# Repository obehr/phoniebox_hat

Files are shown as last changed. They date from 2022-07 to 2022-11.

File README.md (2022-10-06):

# phoniebox_hat
Raspberry Pi HAT for [RPi-Jukebox-RFID](https://github.com/MiczFlor/RPi-Jukebox-RFID)

In 2021 I built a Raspberry PI based Jukebox with RFID reader (see [here](https://github.com/MiczFlor/RPi-Jukebox-RFID/discussions/1331#discussioncomment-433065)). I used a breadboard for buttons and LEDs, USB sound card, ground loop isolator, PAM8403 amplifier. To disconnect the Raspberry from its USB power bank supply on shutdown, I used the awesome [OnOff SHIM](https://shop.pimoroni.com/products/onoff-shim) by Pimoroni.

This is a Raspberry Pi HAT for the 40W GPIO header. It integrates all of those functions on a single custom PCB:
 - DAC (PCM5102a)
 - Amplifier (PAM8406)
 - LED open drain buffers
 - Button inputs with hardware debounce
 - Screw clamps for connecting buttons and LEDs
 - Pin headers for RFID-RC522 and I2C
 - Battery disconnect circuit (the OnOff SHIM is awesome but I didn't want a separate PCB)
 - USB-C connector for power supply

The PCB complies to the official [HAT specification](https://github.com/raspberrypi/hats). Schematic and layout are done in KiCad 6.0. When ordering five PCBs including assembly at JLCPCB, one board costs around 18 USD.

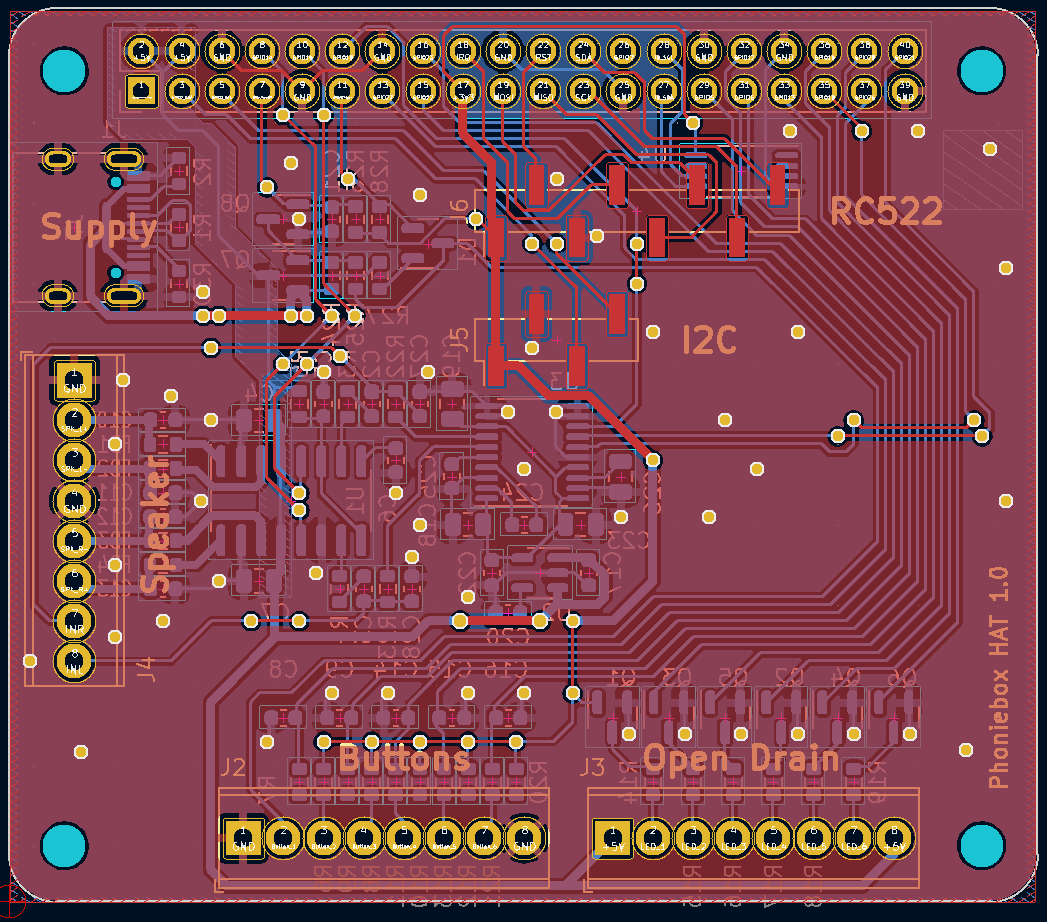
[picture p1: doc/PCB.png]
Screenshot of PCB


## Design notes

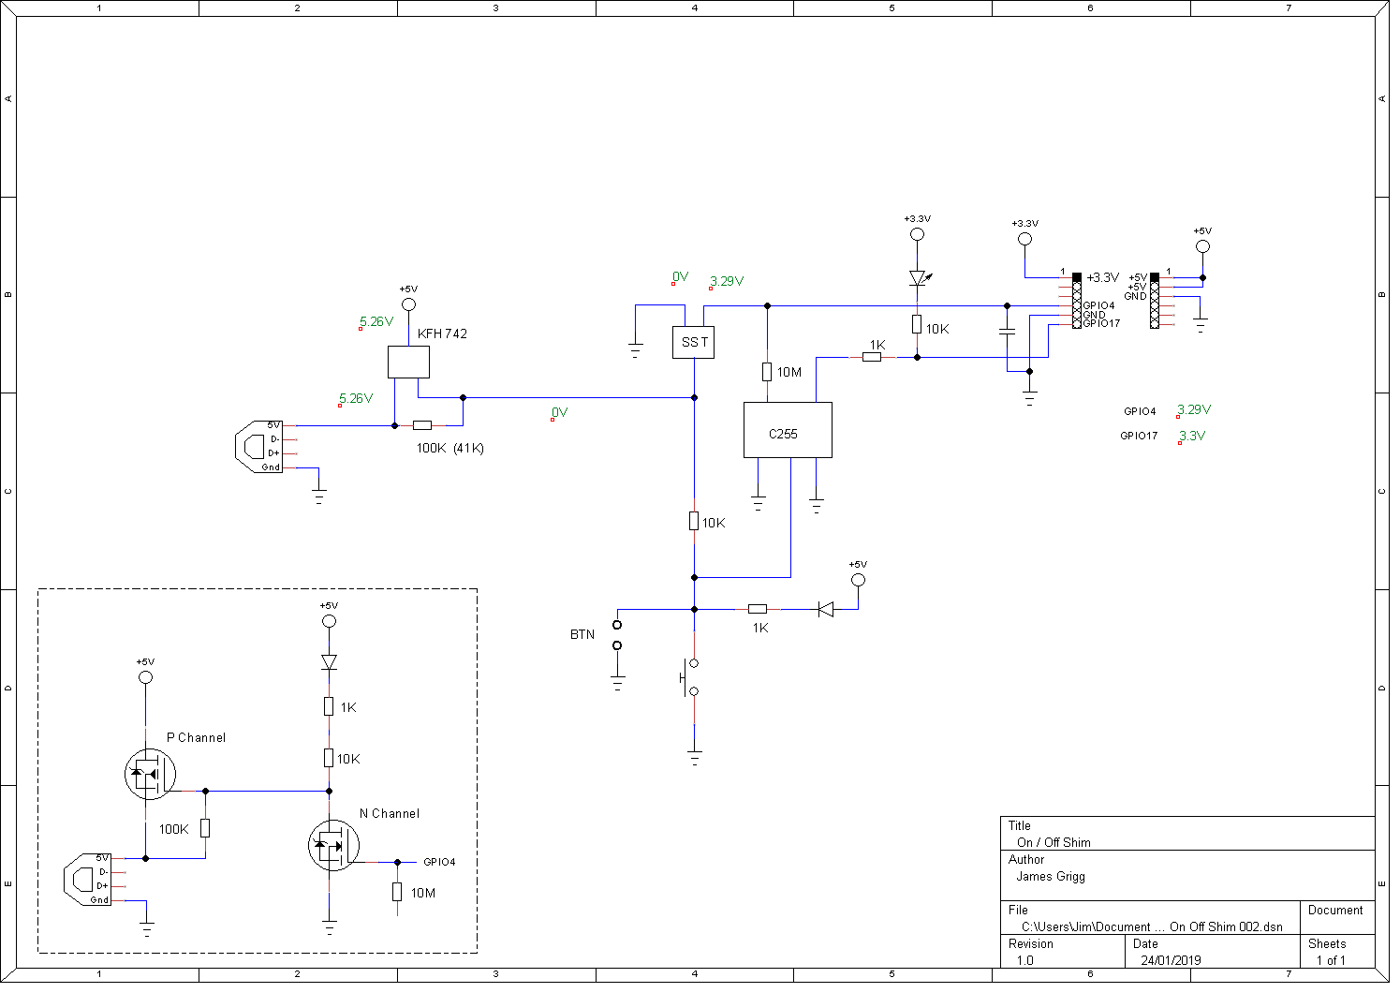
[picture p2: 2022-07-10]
doc/onoff-shim.png

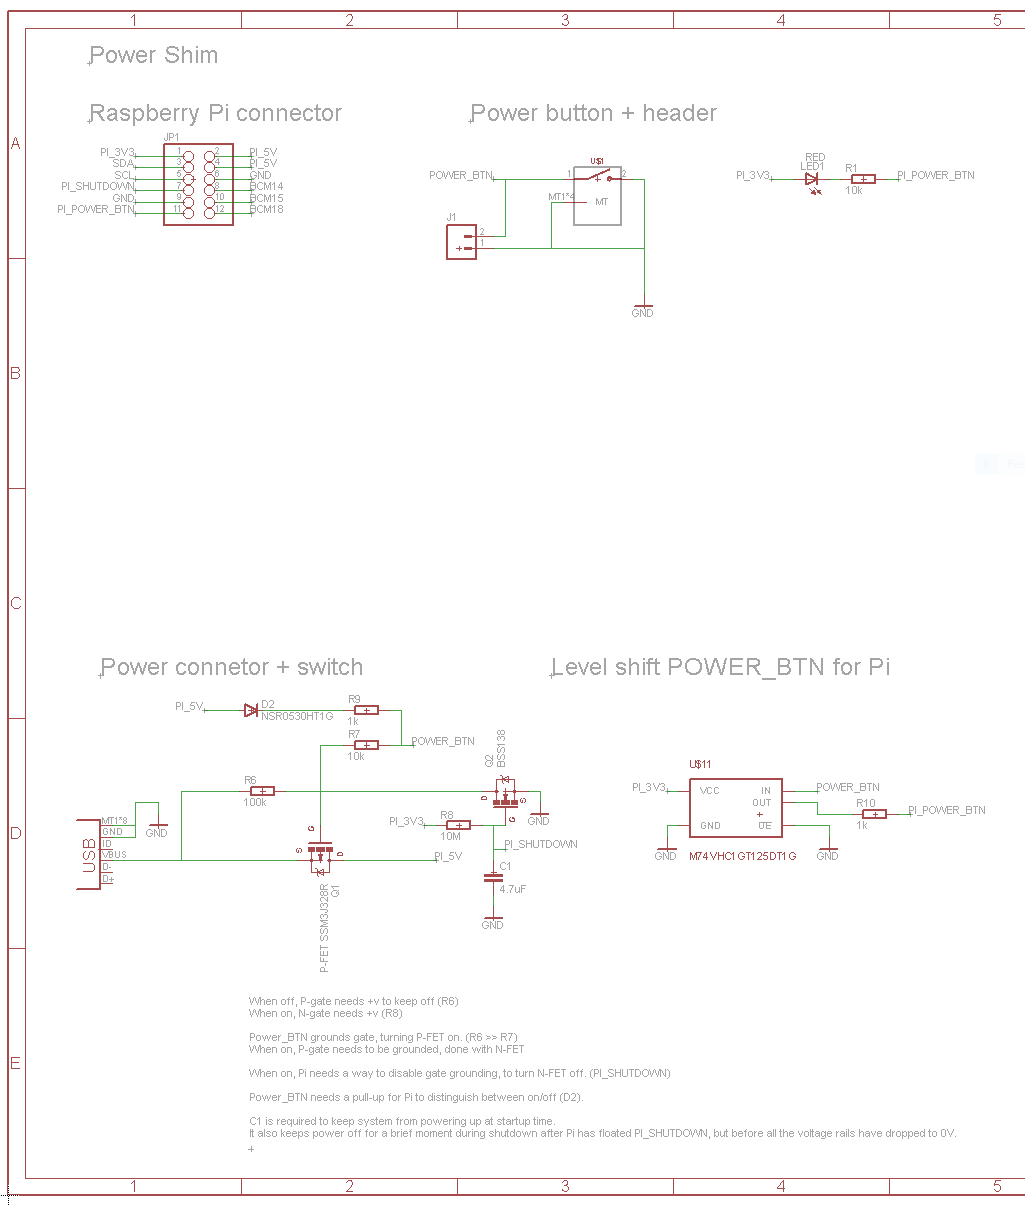
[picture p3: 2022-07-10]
doc/onoff-shim_official.png

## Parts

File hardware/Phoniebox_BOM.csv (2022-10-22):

Comment | Designator | Footprint | LCSC
220p | C10,C11,C12,C13 | Capacitor_SMD:C_0603_1608Metric
100n | C17,C20,C21,C22 | Capacitor_SMD:C_0603_1608Metric
1u | C2,C3,C5,C6,C8,C9,C14,C15,C16 | Capacitor_SMD:C_0603_1608Metric
4u7 | C24,C25 | Capacitor_SMD:C_0603_1608Metric
2n2 | C27,C28 | Capacitor_SMD:C_0603_1608Metric
10u | C4,C7,C18,C19,C23,C26 | Capacitor_SMD:C_0805_2012Metric
BAT54C | D1 | Package_TO_SOT_SMD:SOT-23 | C37704
FerriteBead_Small | FB1,FB2,FB3,FB4 | Resistor_SMD:R_0603_1608Metric | C354394
GPIO | J1 | Connector_PinSocket_2.54mm:PinSocket_2x20_P2.54mm_Vertical | C2977589
Screw_Terminal_01x08 | J2,J3,J4 | TerminalBlock_Phoenix:TerminalBlock_Phoenix_MPT-0,5-8-2.54_1x08_P2.54mm_Horizontal
Conn_01x04_Male | J5 | Connector_PinHeader_2.54mm:PinHeader_1x04_P2.54mm_Vertical_SMD_Pin1Left
Conn_01x08_Male | J6 | Connector_PinHeader_2.54mm:PinHeader_1x08_P2.54mm_Vertical_SMD_Pin1Left
USB_C_Receptacle_USB2.0 | J7 | Connector_USB:USB_C_Receptacle_HRO_TYPE-C-31-M-12 | C165948
2N7002 | Q1,Q2,Q3,Q4,Q5,Q6,Q8 | Package_TO_SOT_SMD:SOT-23 | C350313
AO3401A | Q7 | Package_TO_SOT_SMD:SOT-23 | C15127
10 | R1,R5 | Resistor_SMD:R_0603_1608Metric
100 | R11,R14,R15,R16,R17,R18,R19 | Resistor_SMD:R_0603_1608Metric
5k11 | R2,R30 | Resistor_SMD:R_0603_1608Metric
470 | R22,R23 | Resistor_SMD:R_0603_1608Metric
100k | R24,R26 | Resistor_SMD:R_0603_1608Metric
1k | R27,R28 | Resistor_SMD:R_0603_1608Metric
10k | R3,R4,R25,R29 | Resistor_SMD:R_0603_1608Metric
33k | R6,R7,R8,R9,R10,R12,R13,R20,R21 | Resistor_SMD:R_0603_1608Metric
PAM8406 | U1 | Package_SO:SOP-16_3.9x9.9mm_P1.27mm | C86270
TPS79333-EP | U2 | Package_TO_SOT_SMD:SOT-23-5 | C9840
PCM5102 | U3 | Package_SO:TSSOP-20_4.4x6.5mm_P0.65mm | C107671
CAT24C32 | U4 | Package_SO:TSSOP-8_4.4x3mm_P0.65mm | C94264

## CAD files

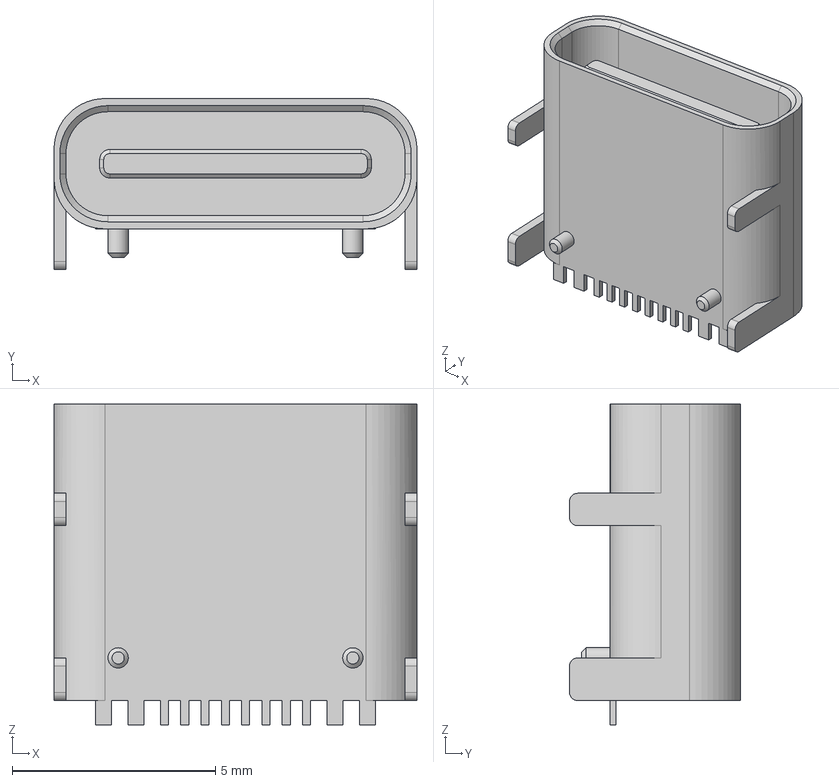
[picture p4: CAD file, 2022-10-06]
hardware/TYPE-C-31-M-12.stp
8.94 x 4.21 x 7.90 mm

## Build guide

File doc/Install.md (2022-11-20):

# Software installation

## OS

Tested with Raspberry Pi OS Lite

## Jukebox

Install RPi-Jukebox-RFID from https://github.com/MiczFlor/RPi-Jukebox-RFID/

The RC522 reader uses SPI0 and the default pin configuration. To configure, run ./run_register_reader.py in src/jukebox and submit the following inputs:

	Reader module number? -> 2 (MFRC522 via SPI)
	Install Python dependencies? -> y
	Auto-configure system settings? -> y
	SPI CEx (CE0=GPIO08, CE1=GPIO7)? -> 0
	IRQ GPIO pin (BCM numbering)? -> 24
	Reset GPIO pin (BCM numbering)? -> 25
	4-byte only legacy mode? -> n
	Do you want to add another RFID reader? -> n

## Battery disconnect circuit

The battery disconnect circuit is compatible with OnOffSHIM. Just run 
	
	curl https://get.pimoroni.com/onoffshim | bash

## Sound card
	
The sound card is compatible with HifiBerry MiniAmp. 

Remove the line

	dtparam=audio=on

from /boot/config.txt if it exists.

If your system uses the vc4-fkms-v3d overlay, make sure, audio is also disabled on this:

	dtoverlay=vc4-fkms-v3d,audio=off

Edit /boot/config.txt and add the following line:

	dtoverlay=hifiberry-dac

Edit or create /etc/asound.conf:

	pcm.hifiberry {
			  type softvol
			  slave.pcm "plughw:0"
			  control.name "Master"
			  control.card 0
	  } 
	pcm.!default {
			  type plug
			  slave.pcm "hifiberry"
	  }

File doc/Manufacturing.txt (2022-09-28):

Generating Gerber Files
---------------------------------------

... and also drill files...

See https://support.jlcpcb.com/article/194-how-to-generate-gerber-and-drill-files-in-kicad-6

Generating BOM and centroid file
---------------------------------------

See https://support.jlcpcb.com/article/84-how-to-generate-the-bom-and-centroid-file-from-kicad

Run script through Schematic editor -> Tools -> Create BOM

Export pos file. Remember to rename columns according to JLC article

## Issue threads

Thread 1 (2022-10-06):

Todo-List before ordering

obehr, 2022-10-06:
The following things should be done before ordering the PCB:

- [ ] Check compliance to Raspberry Pi HAT [specification](https://github.com/raspberrypi/hats)
- [ ] Verify battery disconnect circuit function (prototype and/or simulation)
- [ ] Check DAC circuit according to datasheet / typical application
- [ ] Check Amplifier circuit according to datasheet / typical application
- [ ] Connection of DAC and Amp - will it work like this?
- [ ] Filter size for button debouncing ok or too big?
- [ ] Confirm USB-C connection. Does it allow to draw 3A @ 5V?

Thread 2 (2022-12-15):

All GPIOs driving open drain MOSFETs should have pull-down characteristic

obehr, 2022-12-15:
With pull-down characteristic the open drain output will switch on during startup.

BCM pins GPIO0-GPIO8 have pull-up characteristic by default. Others have pull-down.

GPIO6 is used for Open Drain #1. It should be replaced by any other GPIO > #8.

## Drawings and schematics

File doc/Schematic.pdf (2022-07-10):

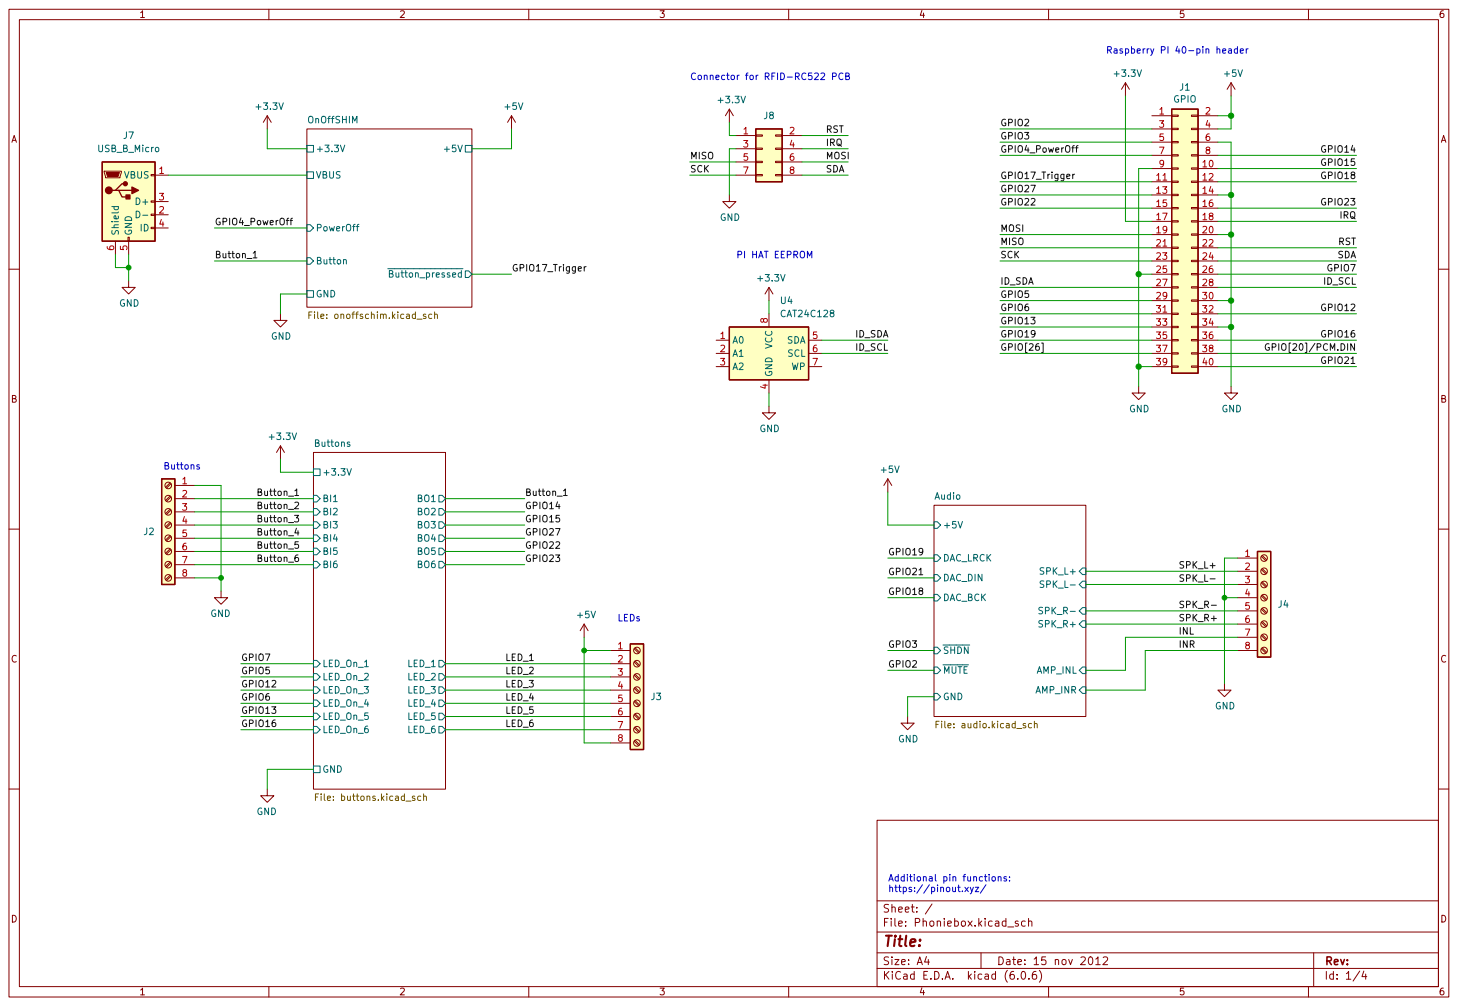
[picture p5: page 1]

Raspberry PI 40-pin header
IRQ

Connector for RFID-RC522 PCB
+3.3V GND

15 | 16 18 20
17

INL PI HAT EEPROM

4 SDA 5 SCL 6 WP 7 VCC

https://pinout.xyz/ LEDs

INR | 8

LED_3 | 4

LED_5 | 6
LED_6 | 7

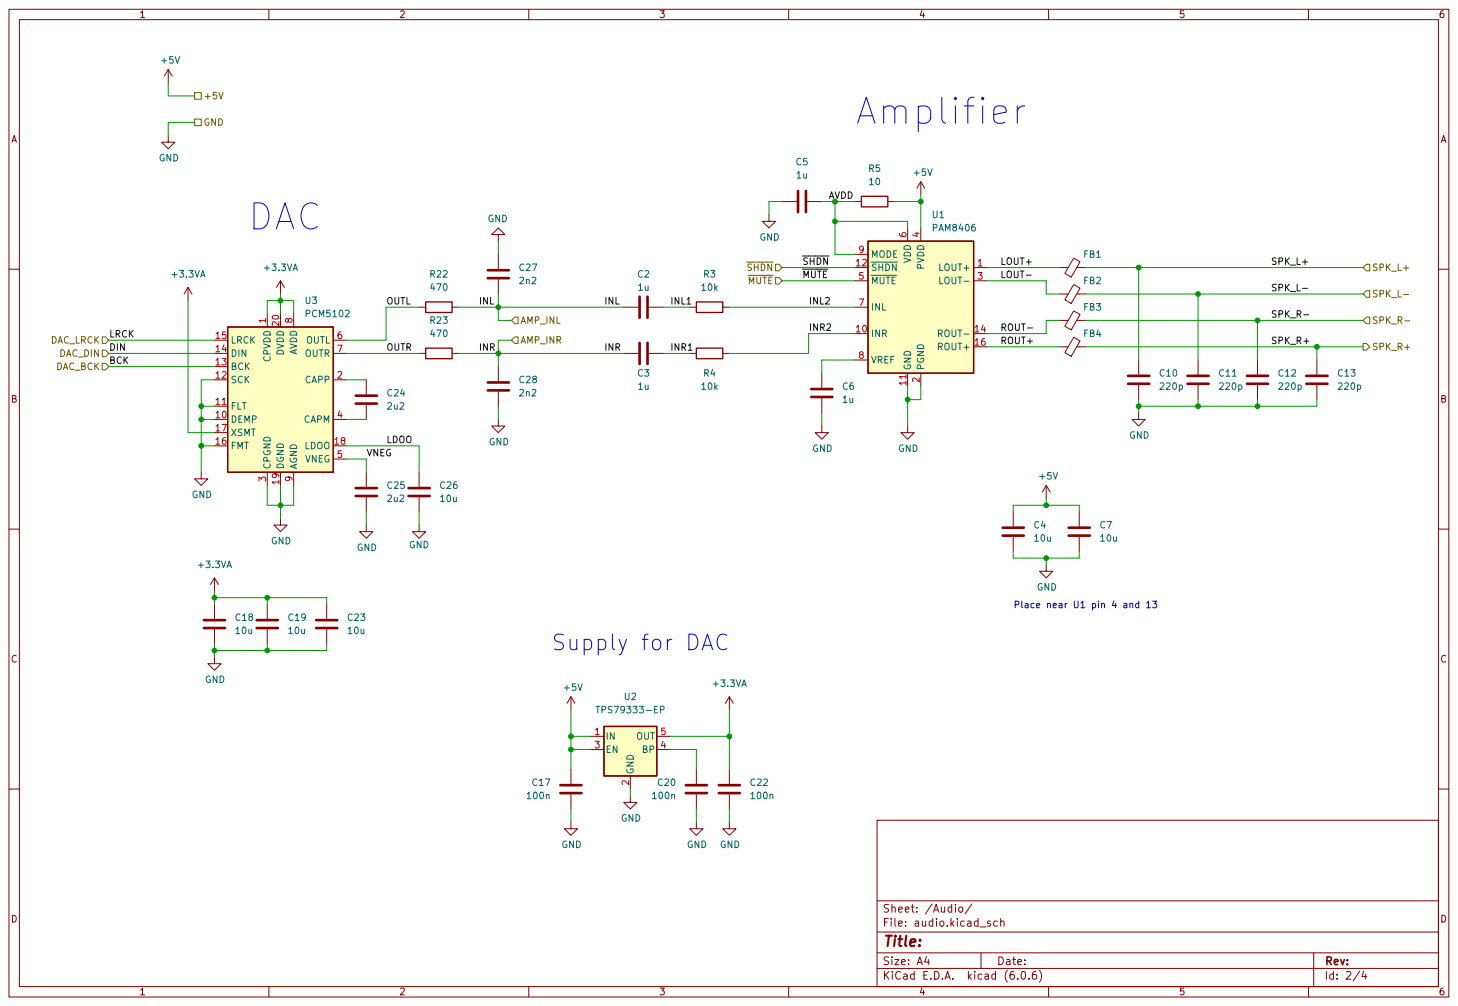
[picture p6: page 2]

1 DEMP 10 FLT 11 SCK 12 BCK 13 DIN 14

3 CAPM 4 VNEG 5 OUTL 6 OUTR 7 AVDD

Place near U1 pin 4 and 13

2 EN 3 BP 4 OUT 5 U2 TPS79333-EP

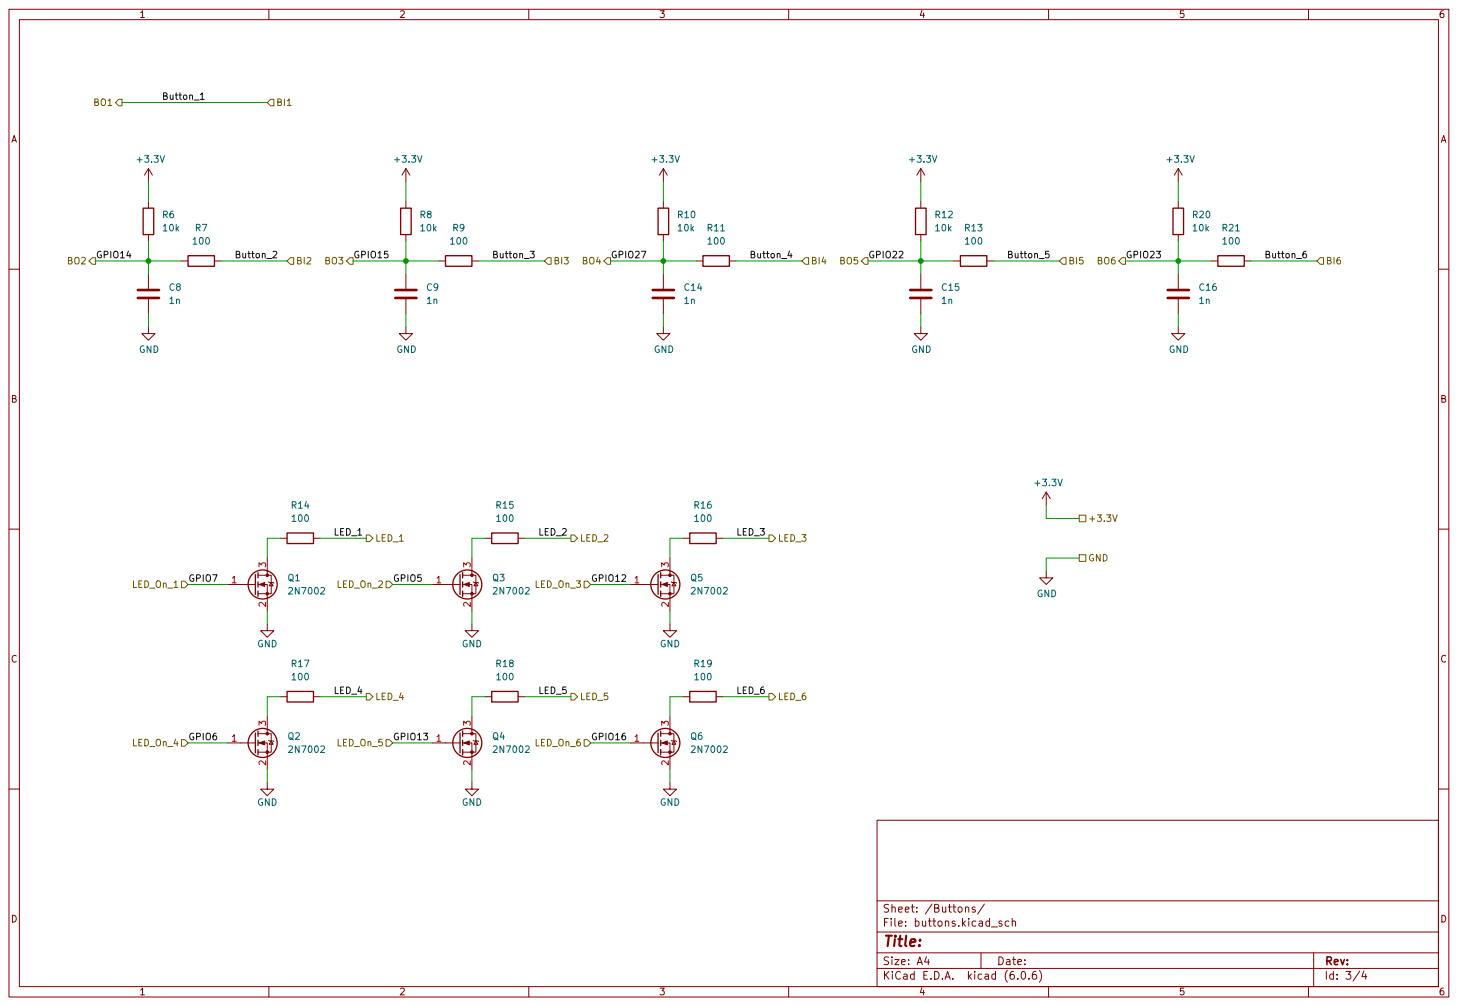
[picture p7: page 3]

File: buttons.kicad_sch Sheet: /Buttons/ R16

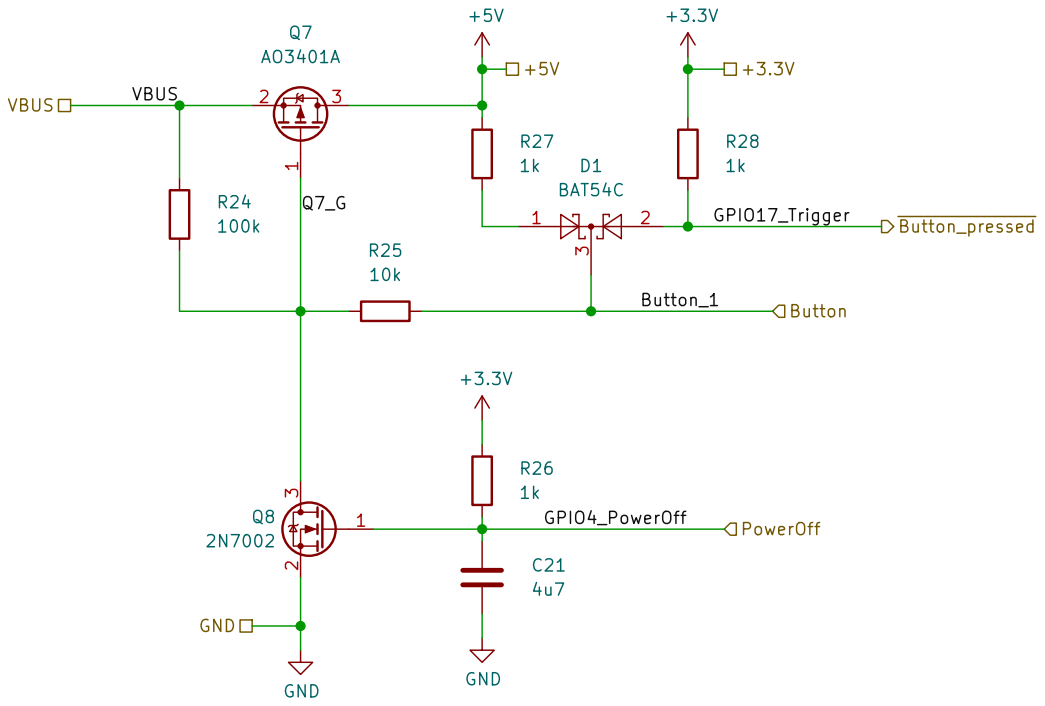
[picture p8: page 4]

File: onoffschim.kicad_sch Sheet: /OnOffSHIM/ GND

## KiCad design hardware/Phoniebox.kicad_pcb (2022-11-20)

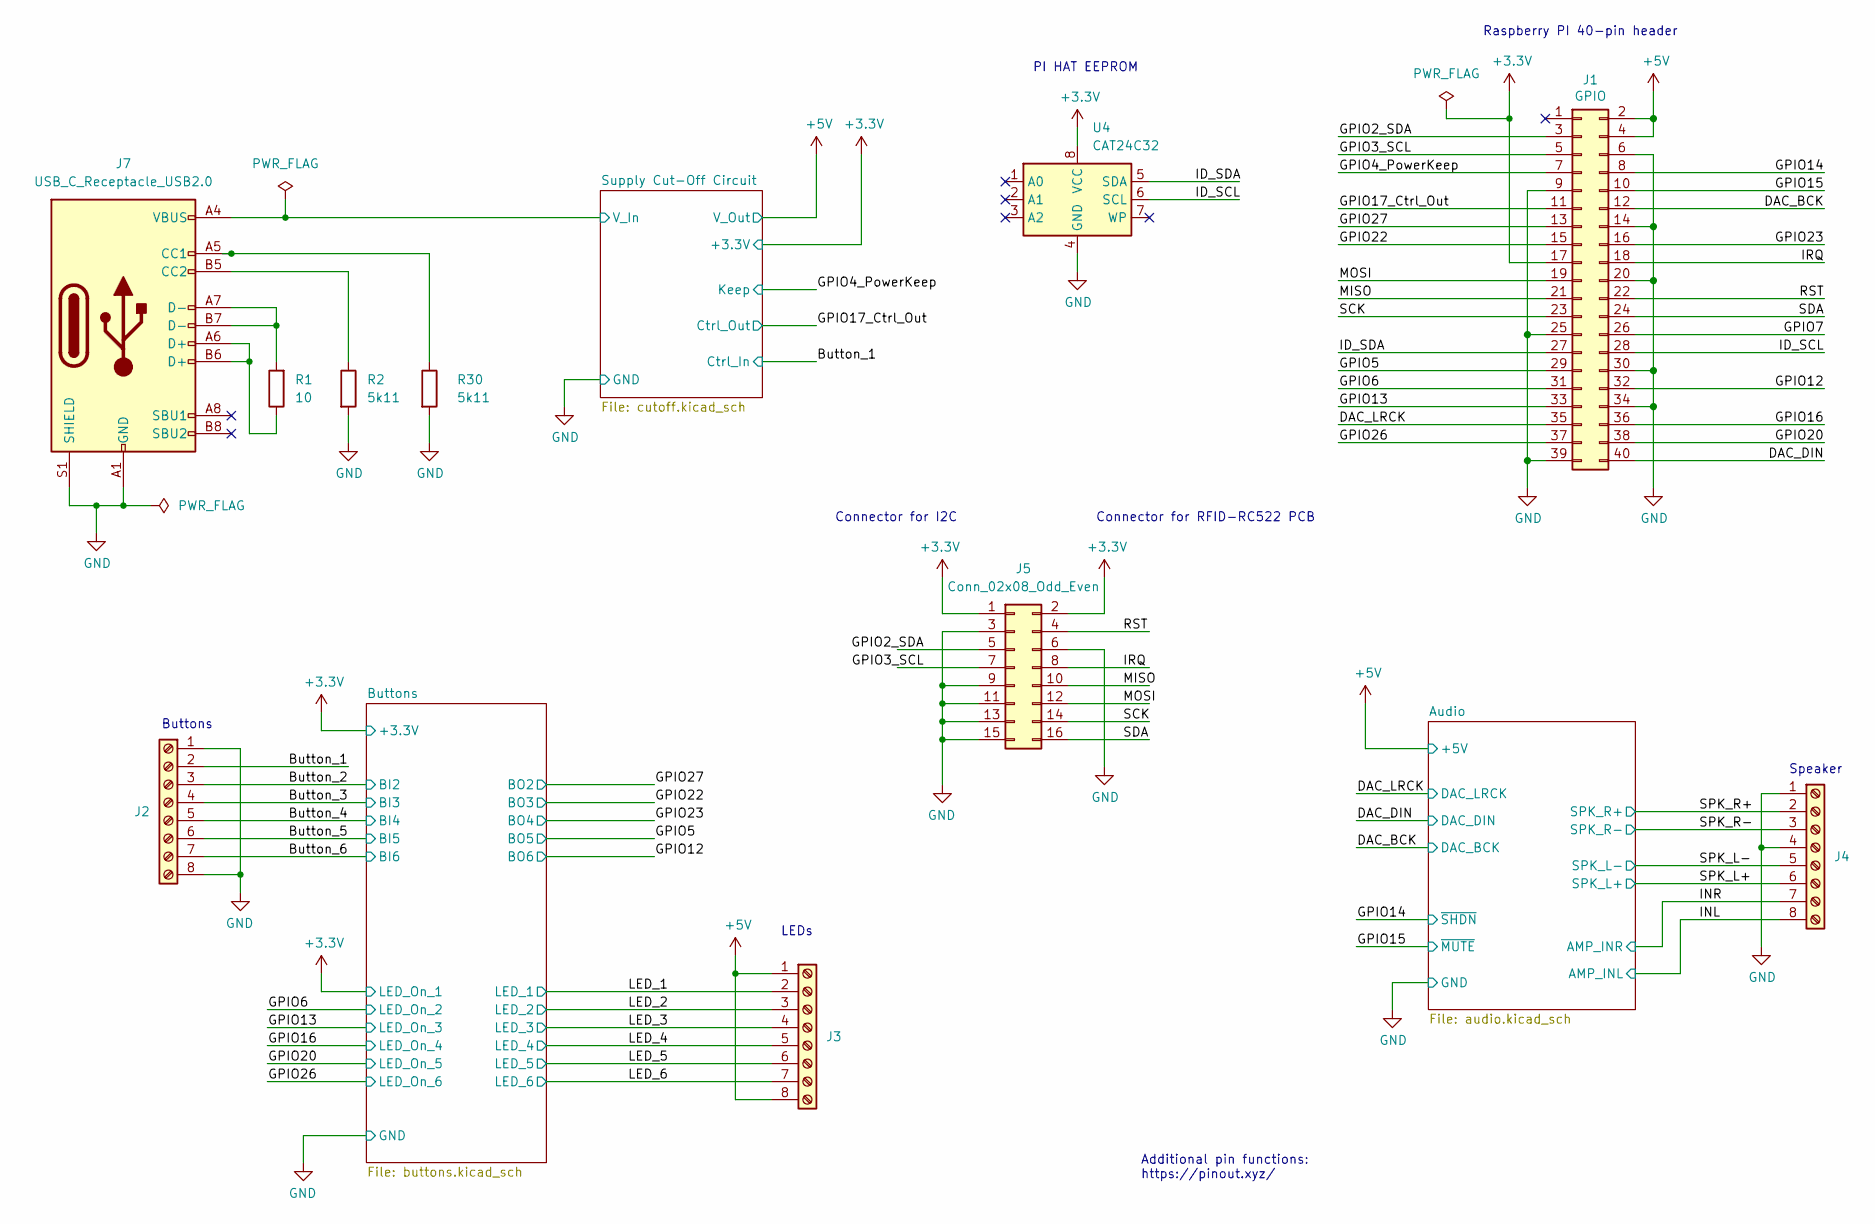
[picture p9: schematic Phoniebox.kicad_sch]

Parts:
J1: GPIO; PinSocket_2x20_P2.54mm_Vertical; LCSC C2977589
J2, J3, J4: Screw_Terminal_01x08; TerminalBlock_Phoenix_MPT-0,5-8-2.54_1x08_P2.54mm_Horizontal
J5: Conn_02x08_Odd_Even; PinHeader_2x08_P2.54mm_Vertical_SMD
J7: USB_C_Receptacle_USB2.0; USB_C_Receptacle_HRO_TYPE-C-31-M-12; LCSC C165948
R1: 10; R_0603_1608Metric
R2, R30: 5k11; R_0603_1608Metric
U4: CAT24C32; TSSOP-8_4.4x3mm_P0.65mm; LCSC C94264

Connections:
+3.3V: J1.17, J5.1, J5.2, U4.8 (VCC); also elsewhere on the board
+5V: J1.2, J1.4, J3.1, J3.8; also elsewhere on the board
/Button_1: J2.2; also elsewhere on the board
/Button_2: J2.3; also elsewhere on the board
/Button_3: J2.4; also elsewhere on the board
/Button_4: J2.5; also elsewhere on the board
/Button_5: J2.6; also elsewhere on the board
/Button_6: J2.7; also elsewhere on the board
/DAC_BCK: J1.12; also elsewhere on the board
/DAC_DIN: J1.40; also elsewhere on the board
/DAC_LRCK: J1.35; also elsewhere on the board
/GPIO2_SDA: J1.3, J5.5
/GPIO3_SCL: J1.5, J5.7
/GPIO4_PowerKeep: J1.7; also elsewhere on the board
/GPIO5: J1.29; also elsewhere on the board
/GPIO6: J1.31; also elsewhere on the board
/GPIO7: J1.26
/GPIO12: J1.32; also elsewhere on the board
/GPIO13: J1.33; also elsewhere on the board
/GPIO14: J1.8; also elsewhere on the board
/GPIO15: J1.10; also elsewhere on the board
/GPIO16: J1.36; also elsewhere on the board
/GPIO17_Ctrl_Out: J1.11; also elsewhere on the board
/GPIO20: J1.38; also elsewhere on the board
/GPIO22: J1.15; also elsewhere on the board
/GPIO23: J1.16; also elsewhere on the board
/GPIO26: J1.37; also elsewhere on the board
/GPIO27: J1.13; also elsewhere on the board
/ID_SCL: J1.28, U4.6 (SCL)
/ID_SDA: J1.27, U4.5 (SDA)
/INL: J4.8; also elsewhere on the board
/INR: J4.7; also elsewhere on the board
/IRQ: J1.18, J5.8
/LED_1: J3.2; also elsewhere on the board
/LED_2: J3.3; also elsewhere on the board
/LED_3: J3.4; also elsewhere on the board
/LED_4: J3.5; also elsewhere on the board
/LED_5: J3.6; also elsewhere on the board
/LED_6: J3.7; also elsewhere on the board
/MISO: J1.21, J5.10
/MOSI: J1.19, J5.12
/RST: J1.22, J5.4
/SCK: J1.23, J5.14
/SDA: J1.24, J5.16
/SPK_L+: J4.6; also elsewhere on the board
/SPK_L-: J4.5; also elsewhere on the board
/SPK_R+: J4.2; also elsewhere on the board
/SPK_R-: J4.3; also elsewhere on the board
/Supply Cut-Off Circuit/V_In: J7.A4 (VBUS), J7.A9 (VBUS), J7.B4 (VBUS), J7.B9 (VBUS); also elsewhere on the board
GND: J1.6, J1.9, J1.14, J1.20, J1.25, J1.30, J1.34, J1.39, J2.1, J2.8, J4.1, J4.4, J5.3, J5.6, J5.9, J5.11, J5.13, J5.15, J7.A1 (GND), J7.A12 (GND), J7.B1 (GND), J7.B12 (GND), J7.S1 (SHIELD), R2.2, R30.2, U4.4 (GND); also elsewhere on the board
unnamed: J7.A5 (CC1), R30.1
unnamed: J7.A6 (D+), J7.B6 (D+), R1.1
unnamed: J7.A7 (D-), J7.B7 (D-), R1.2
unnamed: J7.B5 (CC2), R2.1

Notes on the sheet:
Raspberry PI 40-pin header
Buttons
Additional pin functions: https://pinout.xyz/
LEDs
Connector for RFID-RC522 PCB
Speaker
PI HAT EEPROM
Connector for I2C

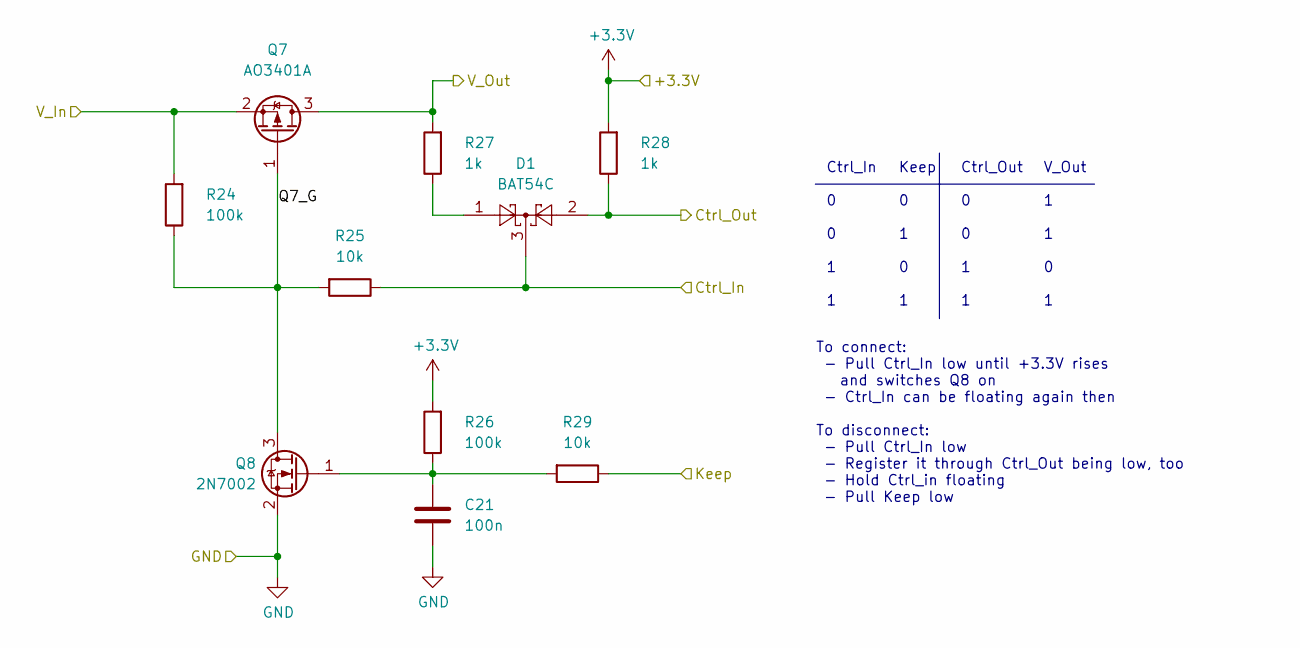
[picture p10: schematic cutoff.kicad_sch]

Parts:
C21: 100n; C_0603_1608Metric
D1: BAT54C; SOT-23; LCSC C37704
Q7: AO3401A; SOT-23; LCSC C15127
Q8: 2N7002; SOT-23; LCSC C350313
R24, R26: 100k; R_0603_1608Metric
R25, R29: 10k; R_0603_1608Metric
R27, R28: 1k; R_0603_1608Metric

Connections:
+3.3V: R26.2, R28.2; also elsewhere on the board
+5V: Q7.3 (D), R27.2; also elsewhere on the board
/Button_1: D1.3, R25.1; also elsewhere on the board
/GPIO4_PowerKeep: R29.1; also elsewhere on the board
/GPIO17_Ctrl_Out: D1.2, R28.1; also elsewhere on the board
/Supply Cut-Off Circuit/Q7_G: Q7.1 (G), Q8.3 (D), R24.1, R25.2
/Supply Cut-Off Circuit/V_In: Q7.2 (S), R24.2; also elsewhere on the board
GND: C21.2, Q8.2 (S); also elsewhere on the board
unnamed: C21.1, Q8.1 (G), R26.1, R29.2
unnamed: D1.1, R27.1

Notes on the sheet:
Ctrl_In 0 0 1 1
V_Out 1 1 0 1
Keep 0 1 0 1
Ctrl_Out 0 0 1 1
To connect: - Pull Ctrl_In low until +3.3V rises and switches Q8 on - Ctrl_In can be floating again then To disconnect: - Pull Ctrl_In low - Register it through Ctrl_Out being low, too - Hold Ctrl_in floating - Pull Keep low

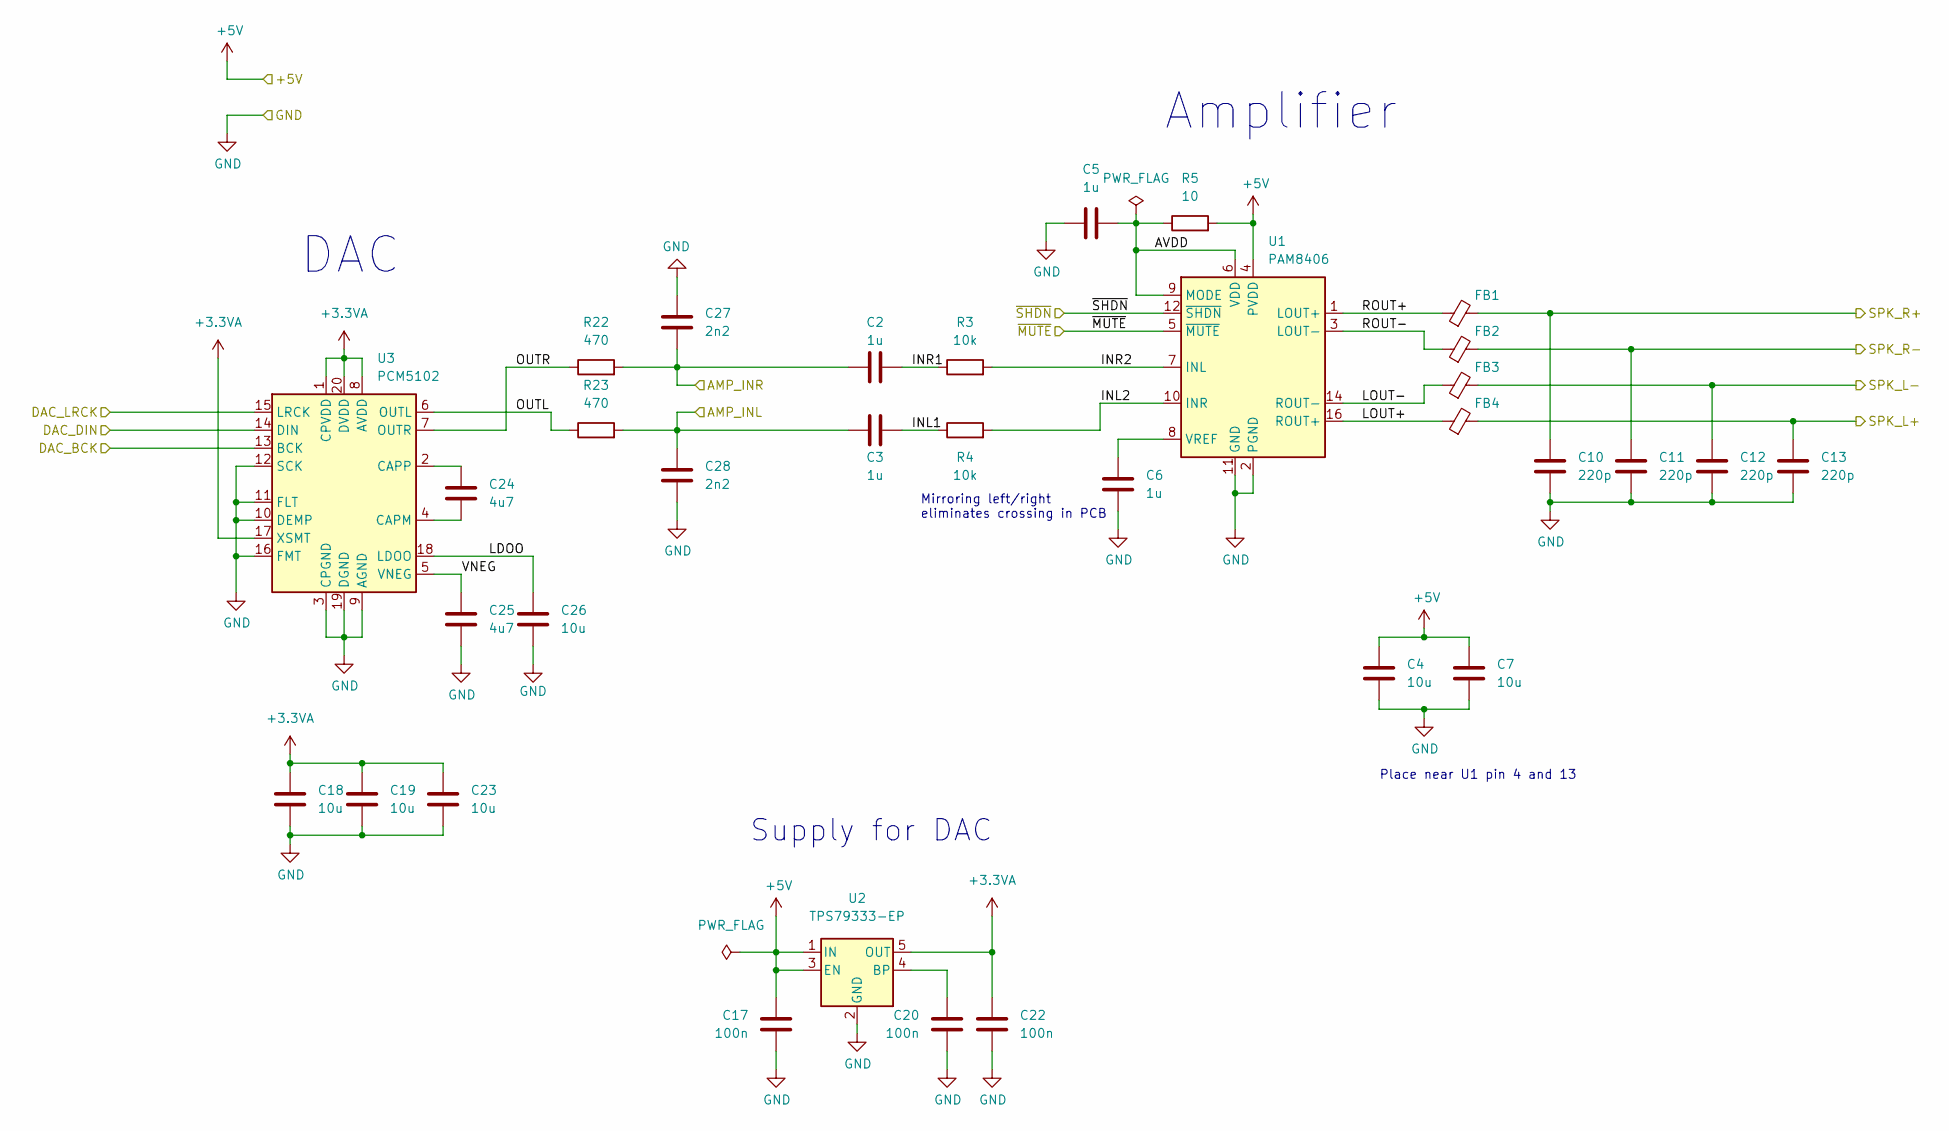
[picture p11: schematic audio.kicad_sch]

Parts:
C2, C3, C5, C6: 1u; C_0603_1608Metric
C4, C7, C18, C19, C23, C26: 10u; C_0805_2012Metric
C10, C11, C12, C13: 220p; C_0603_1608Metric
C17, C20, C22: 100n; C_0603_1608Metric
C24, C25: 4u7; C_0603_1608Metric
C27, C28: 2n2; C_0603_1608Metric
FB1, FB2, FB3, FB4: FerriteBead_Small; R_0603_1608Metric; LCSC C354394
R3, R4: 10k; R_0603_1608Metric
R5: 10; R_0603_1608Metric
R22, R23: 470; R_0603_1608Metric
U1: PAM8406; SOP-16_3.9x9.9mm_P1.27mm; LCSC C86270
U2: TPS79333-EP; SOT-23-5; LCSC C9840
U3: PCM5102; TSSOP-20_4.4x6.5mm_P0.65mm; LCSC C107671

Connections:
+3.3VA: C18.1, C19.1, C22.2, C23.1, U2.5 (OUT), U3.1 (CPVDD), U3.8 (AVDD), U3.17 (XSMT), U3.20 (DVDD)
+5V: C4.1, C7.1, C17.2, R5.2, U1.4 (PVDD), U1.13 (PVDD), U2.1 (IN), U2.3 (EN); also elsewhere on the board
/Audio/AVDD: C5.2, R5.1, U1.6 (VDD), U1.9 (MODE)
/Audio/INL1: C3.2, R4.1
/Audio/INL2: R4.2, U1.10 (INR)
/Audio/INR1: C2.2, R3.1
/Audio/INR2: R3.2, U1.7 (INL)
/Audio/LDOO: C26.1, U3.18 (LDOO)
/Audio/LOUT+: FB4.1, U1.16 (ROUT+)
/Audio/LOUT-: FB3.1, U1.14 (ROUT-)
/Audio/OUTL: R23.1, U3.6 (OUTL)
/Audio/OUTR: R22.1, U3.7 (OUTR)
/Audio/ROUT+: FB1.1, U1.1 (LOUT+)
/Audio/ROUT-: FB2.1, U1.3 (LOUT-)
/Audio/VNEG: C25.1, U3.5 (VNEG)
/DAC_BCK: U3.13 (BCK); also elsewhere on the board
/DAC_DIN: U3.14 (DIN); also elsewhere on the board
/DAC_LRCK: U3.15 (LRCK); also elsewhere on the board
/GPIO14: U1.12 (~SHDN); also elsewhere on the board
/GPIO15: U1.5 (~MUTE); also elsewhere on the board
/INL: C3.1, C28.1, R23.2; also elsewhere on the board
/INR: C2.1, C27.2, R22.2; also elsewhere on the board
/SPK_L+: C13.1, FB4.2; also elsewhere on the board
/SPK_L-: C12.1, FB3.2; also elsewhere on the board
/SPK_R+: C10.1, FB1.2; also elsewhere on the board
/SPK_R-: C11.1, FB2.2; also elsewhere on the board
GND: C4.2, C5.1, C6.2, C7.2, C10.2, C11.2, C12.2, C13.2, C17.1, C18.2, C19.2, C20.1, C22.1, C23.2, C25.2, C26.2, C27.1, C28.2, U1.2 (PGND), U1.11 (GND), U1.15 (PGND), U2.2 (GND), U3.3 (CPGND), U3.9 (AGND), U3.10 (DEMP), U3.11 (FLT), U3.12 (SCK), U3.16 (FMT), U3.19 (DGND); also elsewhere on the board
unnamed: C6.1, U1.8 (VREF)
unnamed: C20.2, U2.4 (BP)
unnamed: C24.1, U3.2 (CAPP)
unnamed: C24.2, U3.4 (CAPM)

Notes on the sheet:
DAC
Supply for DAC
Place near U1 pin 4 and 13
Mirroring left/right eliminates crossing in PCB
Amplifier

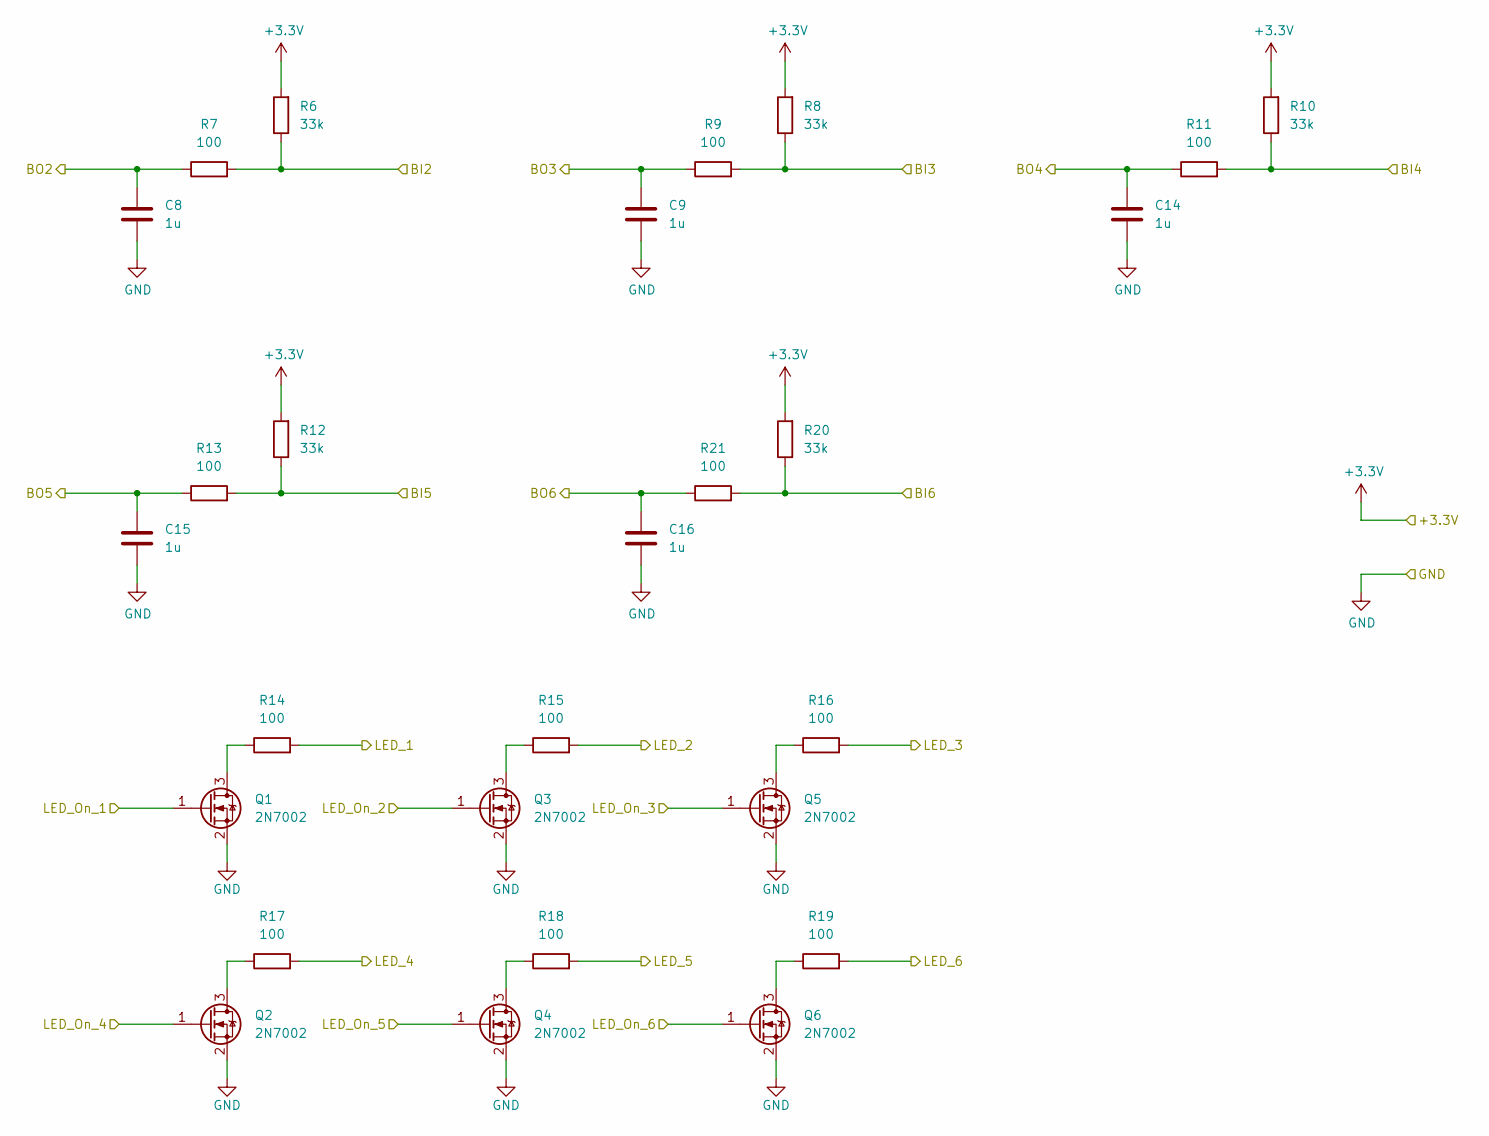
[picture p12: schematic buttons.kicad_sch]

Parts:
C8, C9, C14, C15, C16: 1u; C_0603_1608Metric
Q1, Q2, Q3, Q4, Q5, Q6: 2N7002; SOT-23; LCSC C350313
R6, R8, R10, R12, R20: 33k; R_0603_1608Metric
R7, R9, R11, R13, R14, R15, R16, R17, R18, R19, R21: 100; R_0603_1608Metric

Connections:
+3.3V: Q1.1 (G), R6.2, R8.2, R10.2, R12.2, R20.2; also elsewhere on the board
/Button_2: R6.1, R7.2; also elsewhere on the board
/Button_3: R8.1, R9.2; also elsewhere on the board
/Button_4: R10.1, R11.2; also elsewhere on the board
/Button_5: R12.1, R13.2; also elsewhere on the board
/Button_6: R20.1, R21.2; also elsewhere on the board
/GPIO5: C15.1, R13.1; also elsewhere on the board
/GPIO6: Q3.1 (G); also elsewhere on the board
/GPIO12: C16.1, R21.1; also elsewhere on the board
/GPIO13: Q5.1 (G); also elsewhere on the board
/GPIO16: Q2.1 (G); also elsewhere on the board
/GPIO20: Q4.1 (G); also elsewhere on the board
/GPIO22: C9.1, R9.1; also elsewhere on the board
/GPIO23: C14.1, R11.1; also elsewhere on the board
/GPIO26: Q6.1 (G); also elsewhere on the board
/GPIO27: C8.1, R7.1; also elsewhere on the board
/LED_1: R14.2; also elsewhere on the board
/LED_2: R15.2; also elsewhere on the board
/LED_3: R16.2; also elsewhere on the board
/LED_4: R17.2; also elsewhere on the board
/LED_5: R18.2; also elsewhere on the board
/LED_6: R19.2; also elsewhere on the board
GND: C8.2, C9.2, C14.2, C15.2, C16.2, Q1.2 (S), Q2.2 (S), Q3.2 (S), Q4.2 (S), Q5.2 (S), Q6.2 (S); also elsewhere on the board
unnamed: Q1.3 (D), R14.1
unnamed: Q2.3 (D), R17.1
unnamed: Q3.3 (D), R15.1
unnamed: Q4.3 (D), R18.1
unnamed: Q5.3 (D), R16.1
unnamed: Q6.3 (D), R19.1

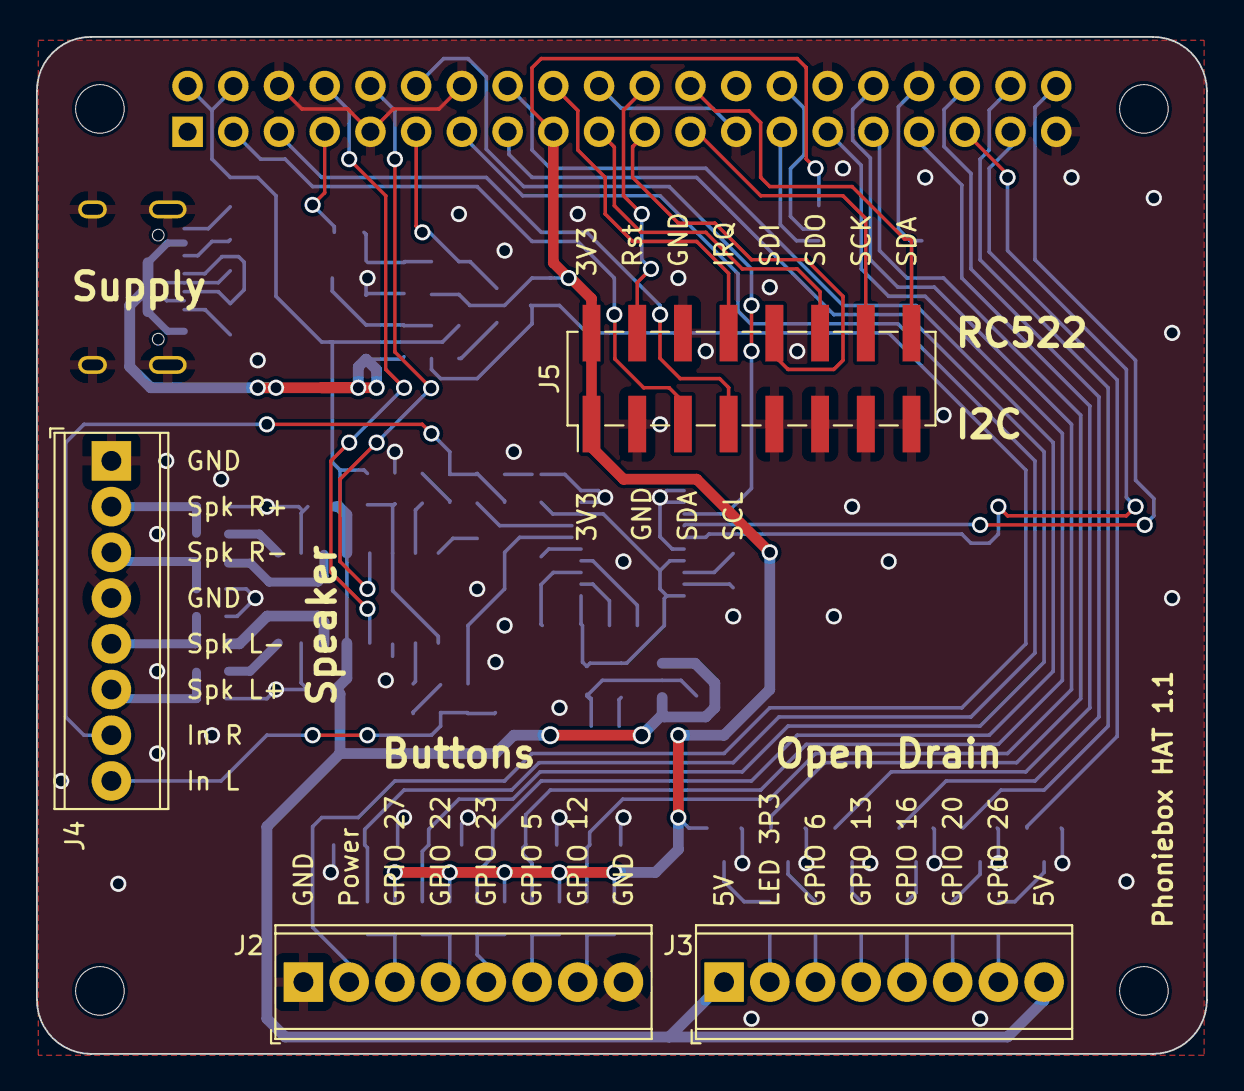
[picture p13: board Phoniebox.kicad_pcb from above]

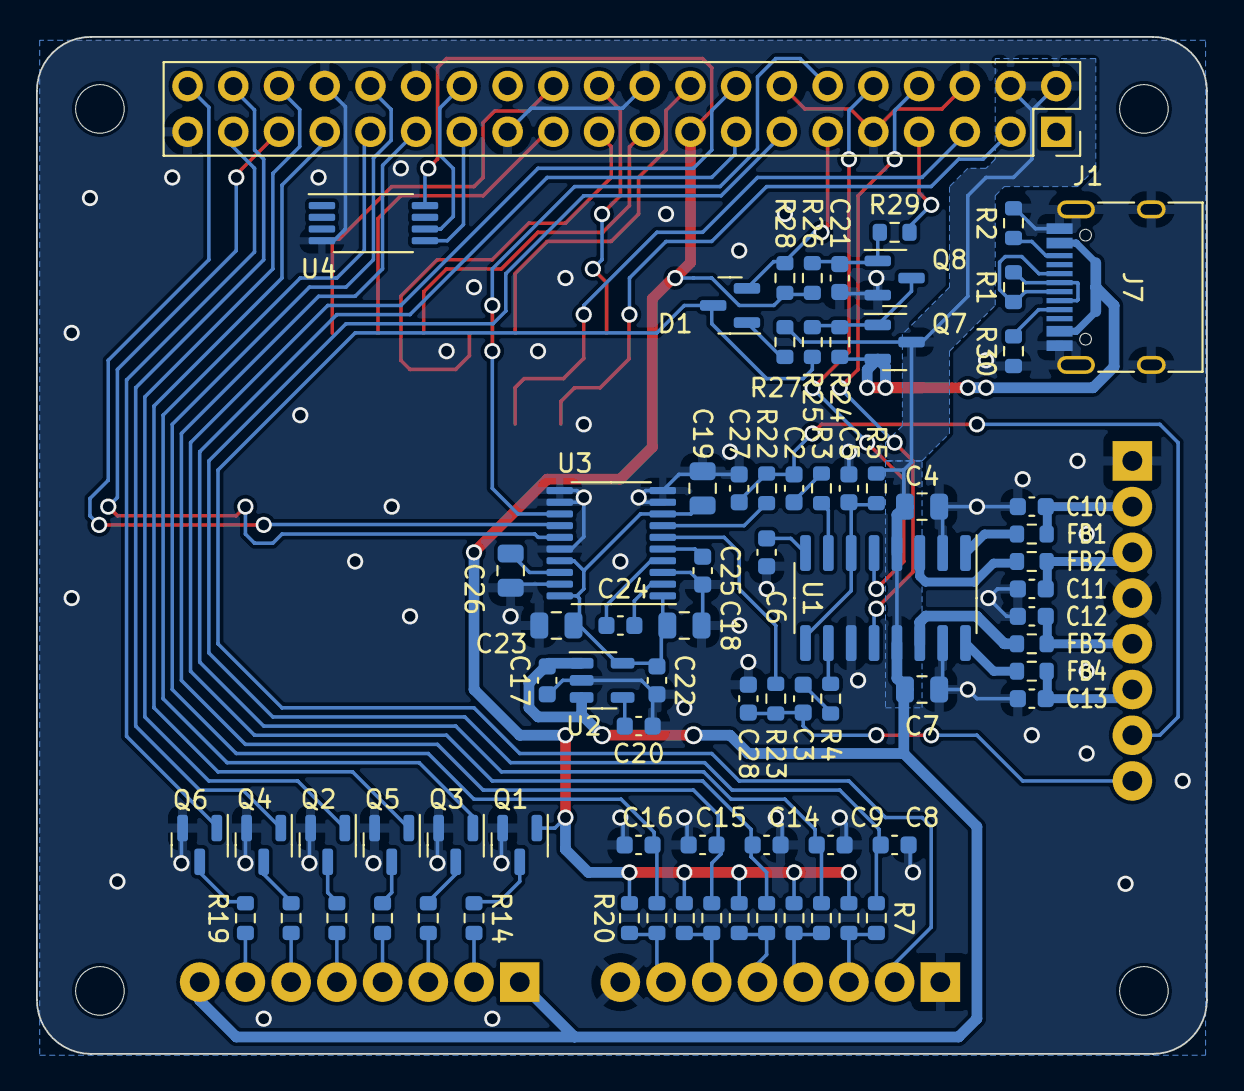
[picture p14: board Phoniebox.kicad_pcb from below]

Board: 2 copper layers, 65.0 x 56.5 mm, 84 parts (76 on the bottom side), 80 nets.

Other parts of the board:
MH1, MH2, MH3, MH4: MountingHole_2.7mm_M2.5

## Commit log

2022-07-10 Add OnOff-SHIM circuit to PCB
    [Phoniebox.kicad_pcb, Phoniebox.kicad_sch]
2022-07-10 Fix DRC errors/warnings, Add round edges for PCB.
    [Phoniebox.kicad_pcb, Phoniebox.kicad_sch]
2022-07-10 Create hierachical schematic sheets for audio/LED/buttons.
    [Phoniebox.kicad_pcb, Phoniebox.kicad_sch, audio.kicad_sch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]
2022-07-10 Place OnOffSHIM circuit on separate page.
    [Phoniebox.kicad_pcb, Phoniebox.kicad_sch, audio.kicad_sch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]
2022-07-10 Export schematic and PCB image
    [Phoniebox.kicad_pcb]
2022-07-11 Add I2C header for displays. Mute/SHDN now controlled by previously unused GPIO20/26. LED1 is now hardwired to ON=V3P3 high. GPIO7 would still be available to control LED1. Change debounce circuit to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
    [Phoniebox.kicad_pcb, Phoniebox.kicad_sch, buttons.kicad_sch]
2022-07-11 Update README.md
    Now with I2C header.
2022-08-21 Add BOM descriptions and JLC PCB LCSC part numbers. Generate gerber, drill and pick-and-place files.
    [Phoniebox-B_Cu.gbl, Phoniebox-B_Mask.gbs, Phoniebox-B_Silkscreen.gbo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]
2022-08-27 Place on/off SHIM and EEPROM on bot
    [Phoniebox-B_Cu.gbl, Phoniebox-B_Mask.gbs, Phoniebox-B_Silkscreen.gbo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]
2022-09-27 Replace micro USB connector with USB-C type connector. DRC errors exist.
    [Phoniebox.kicad_pcb, Phoniebox.kicad_sch]
2022-09-28 Fixed gridd issues. Properly added USB-C connector. Fixed DRC errors.
    [Phoniebox-B_Cu.gbl, Phoniebox-B_Paste.gbp, Phoniebox-B_Silkscreen.gbo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]
2022-09-28 Update gerber files.
    [Phoniebox-B_Cu.gbl, Phoniebox-B_Mask.gbs, Phoniebox-B_Paste.gbp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]
2022-09-29 Smaller high value caps. Standard R/C footprints instead of hand solder.
    [Phoniebox.kicad_pcb, Phoniebox.kicad_sch, Phoniebox_BOM.csv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]
2022-09-29 Move a lot of parts. Switch audio l/r (only in schematic). Next step: Apply in PCB.
    [Phoniebox.kicad_pcb, Phoniebox.kicad_sch, audio.kicad_sch]
2022-10-01 Moved DAC. Replace pin headers with single row SMD ones (compatible with RC522/display PCBs to connect).
    [Phoniebox-B_Cu.gbl, Phoniebox-B_Mask.gbs, Phoniebox-B_Paste.gbp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]
2022-10-01 Size 0805 for 10uF capacitors.
    [Phoniebox-B_Cu.gbl, Phoniebox-B_Mask.gbs, Phoniebox-B_Paste.gbp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]
2022-10-01 Update PCB pic
2022-10-06 Add USB-C 3D model. Add pinning info in silkscreen for all connectors.
    [Phoniebox.kicad_pcb, TYPE-C-31-M-12.stp]
2022-10-21 Fix all ERC warnings. Replace 4u7 capacitor in cut-off circuit by 100 nF cap and 10 kOhm in series to reduce stress on Raspi GPIO.
    [JLCPCB-Example-pos.csv, Phoniebox-B_Cu.gbl, Phoniebox-B_Mask.gbs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]
2022-10-22 Update BOM
    [Phoniebox_BOM.csv]
2022-11-18 Button resistors must be 100 Ohms
    [Phoniebox.kicad_sch, buttons.kicad_sch]
2022-11-20 Replaced both single row connectors for RC522,I2C by one two row connector. Speaker left and right were mixed in top level schematic -> fixed net names and silkscreen text.
    [Phoniebox.kicad_pcb, Phoniebox.kicad_sch]
